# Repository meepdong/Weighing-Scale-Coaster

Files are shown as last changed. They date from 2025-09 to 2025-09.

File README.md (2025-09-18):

# Weighing Scale Coaster
A precision coffee scale built around the HX711 load cell amplifier, optimized for responsiveness and stability. Designed for baristas, tinkerers, and embedded engineers who care about both performance and personality.

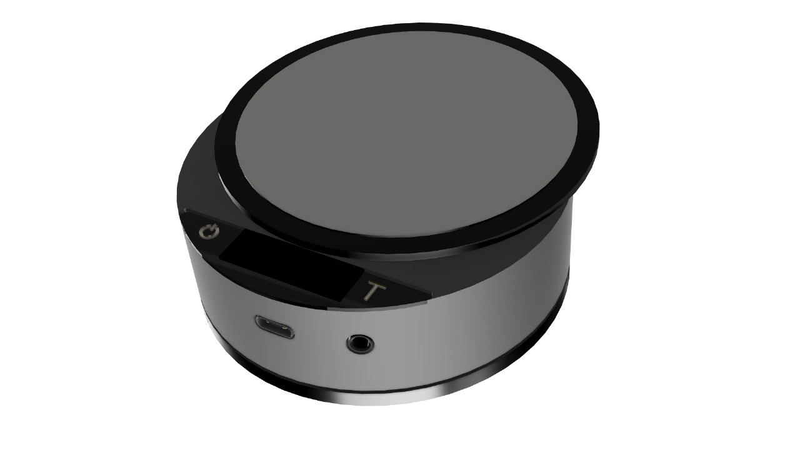
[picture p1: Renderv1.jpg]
Weighing Scale Coaster

## Features
• 	HX711-based load cell interface with high-resolution weight readings

• 	Reference-inspired filtering pipeline adapted from Analog Devices' weigh scale design

• 	OLED display with expressive dome-shaped eyes and smile animation

• 	Timer with short press toggle and long press reset

• 	Flicker-free weight display using hysteresis and trimmed averaging

• 	Designed for both Raspberry Pi Pico W and Seeed Studio XIAO ESP32-C6

## Hardware Overview
### Components
• 	HX711 Load Cell Amplifier

• 	5 kg Load Cell

• 	SSD1306 OLED Display (128×32)

• 	Two momentary push buttons (Tare + Timer) . To be replaced with capacitive touch 

• 	Microcontroller: Raspberry Pi Pico W or Seeed Studio XIAO ESP32-C6

## Wiring Table

| Pin on OLED | Pin on HX711 | Pin on Pico W | Pin on XIAO ESP32-C6 |
|---|---|---|---|
| VCC | VCC | 3.3V | 3.3V |
| GND | GND | GND | GND | 
| Data (DT) | DT | GPIO 16 | GPIO 10 |
| Clock (SCK) | SCK | GPIO 17 | GPIO 11 |
| OLED SDA | SDA | GPIO 4 | GPIO 4 | 
| OLED SCL | SCL | GPIO 5 | GPIO 5 |
| Tare Button | - | GPIO 18 | GPIO 6 |
| Timer Button  | - | GPIO 19 | GPIO 7 |

## Load Cell Algorithm
This project adapts the signal processing architecture from Analog Devices' weigh scale reference design to the HX711.
Filtering Pipeline

• 	Trimmed Moving Average: Removes min/max outliers from a rolling window to suppress noise while preserving step response.

• 	Step Detection: Detects real weight changes using dual-threshold logic and pre-fills the filter buffer to skip lag.

• 	Display Hysteresis: Prevents flicker by suppressing small changes below a threshold.

### Why It Works
• 	HX711 is a 24-bit sigma-delta ADC with built-in gain and ratiometric measurement.

• 	Filtering compensates for its limited noise-free resolution and slow sample rate.

• 	The result: smooth, stable, and responsive weight readings even with low-cost hardware.

## User Interaction

OLED shows timer and weight. Startup animation includes blinking eyes and a smile. A Hall effect sensor to be integrated for a lid-activated deep sleep and wake mode.

Future Improvements
• 	Calibration helper script for computing 

• 	BLE or Wi-Fi integration for remote brew tracking

• 	Capacitive touch buttons

Credits
Built by Maurice D'Moss, mechanical product design engineer with a passion for coffee and embedded systems.
Filtering architecture inspired by Analog Devices' weigh scale reference design.

## License

This project is licensed under the [Creative Commons Attribution-NonCommercial 4.0 International License](https://creativecommons.org/licenses/by-nc/4.0/).

You are free to use, modify, and share this project for personal and educational purposes.  
Commercial use is not permitted without explicit permission from the author.

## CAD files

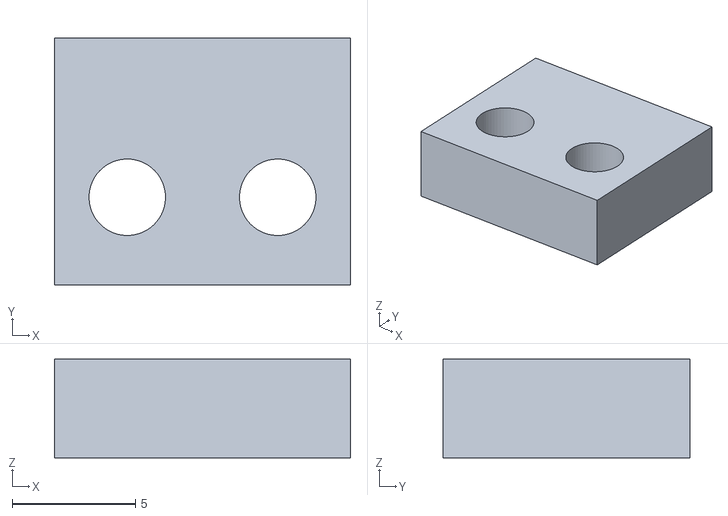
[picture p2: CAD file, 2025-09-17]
CAD/Spacer small.stl
12.0 x 10.0 x 4.00

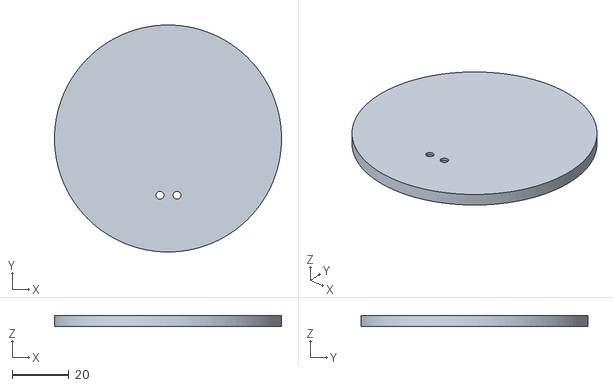
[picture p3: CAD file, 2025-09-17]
CAD/Plate test.stl
80.0 x 80.0 x 4.00

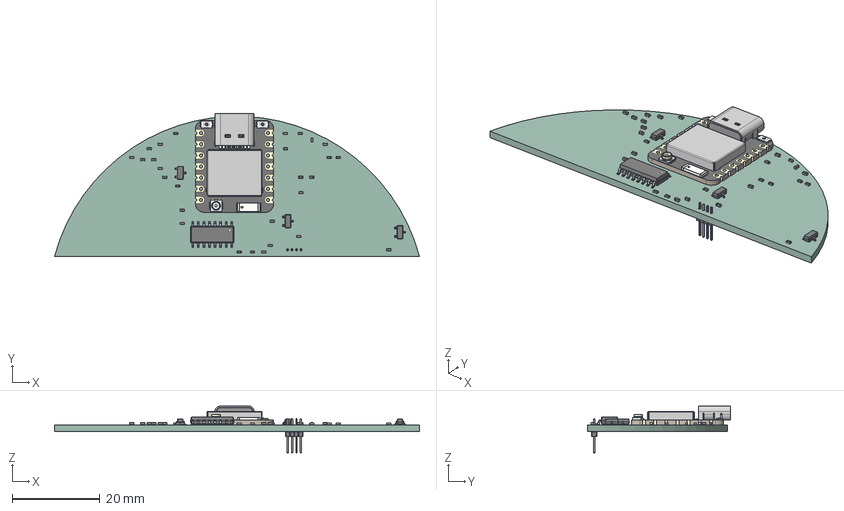
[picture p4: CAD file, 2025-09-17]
CAD/WeighingScalePCB.step
83.1 x 32.5 x 10.7 mm
SOIC-16_3.9x9.9mm_P1.27mm
C_0402_1005Metric x 16
R_0402_1005Metric x 12
SOT-23 x 3
BOSS-EXTRUDE14_8_
BOSS-EXTRUDE7_4_
BOSS-EXTRUDE7_3_
BOSS-EXTRUDE14_4_
BOSS-EXTRUDE14_2_
BOSS-EXTRUDE14_11_
BOSS-EXTRUDE7_7_
BOSS-EXTRUDE14_9_
BOSS-EXTRUDE14_3_
BOSS-EXTRUDE14_7_
MIRROR2
BOSS-EXTRUDE14_5_
BOSS-EXTRUDE14_12_
BOSS-EXTRUDE7_8_
BOSS-EXTRUDE7_1_
BOSS-EXTRUDE14_10_
BOSS-EXTRUDE7_9_
BOSS-EXTRUDE14_6_
BOSS-EXTRUDE14_1_
BOSS-EXTRUDE7_6_
BOSS-EXTRUDE7_2_
CUT-EXTRUDE5
BOSS-EXTRUDE7_5_
U.FL Connector v1
Shield
SKTAAAE010 v1 x 2
KH5220-A36 (Ceramic Antenna) v2
PinHeader_1x04_P1.00mm_Vertical
WeighingScalePCB_PCB

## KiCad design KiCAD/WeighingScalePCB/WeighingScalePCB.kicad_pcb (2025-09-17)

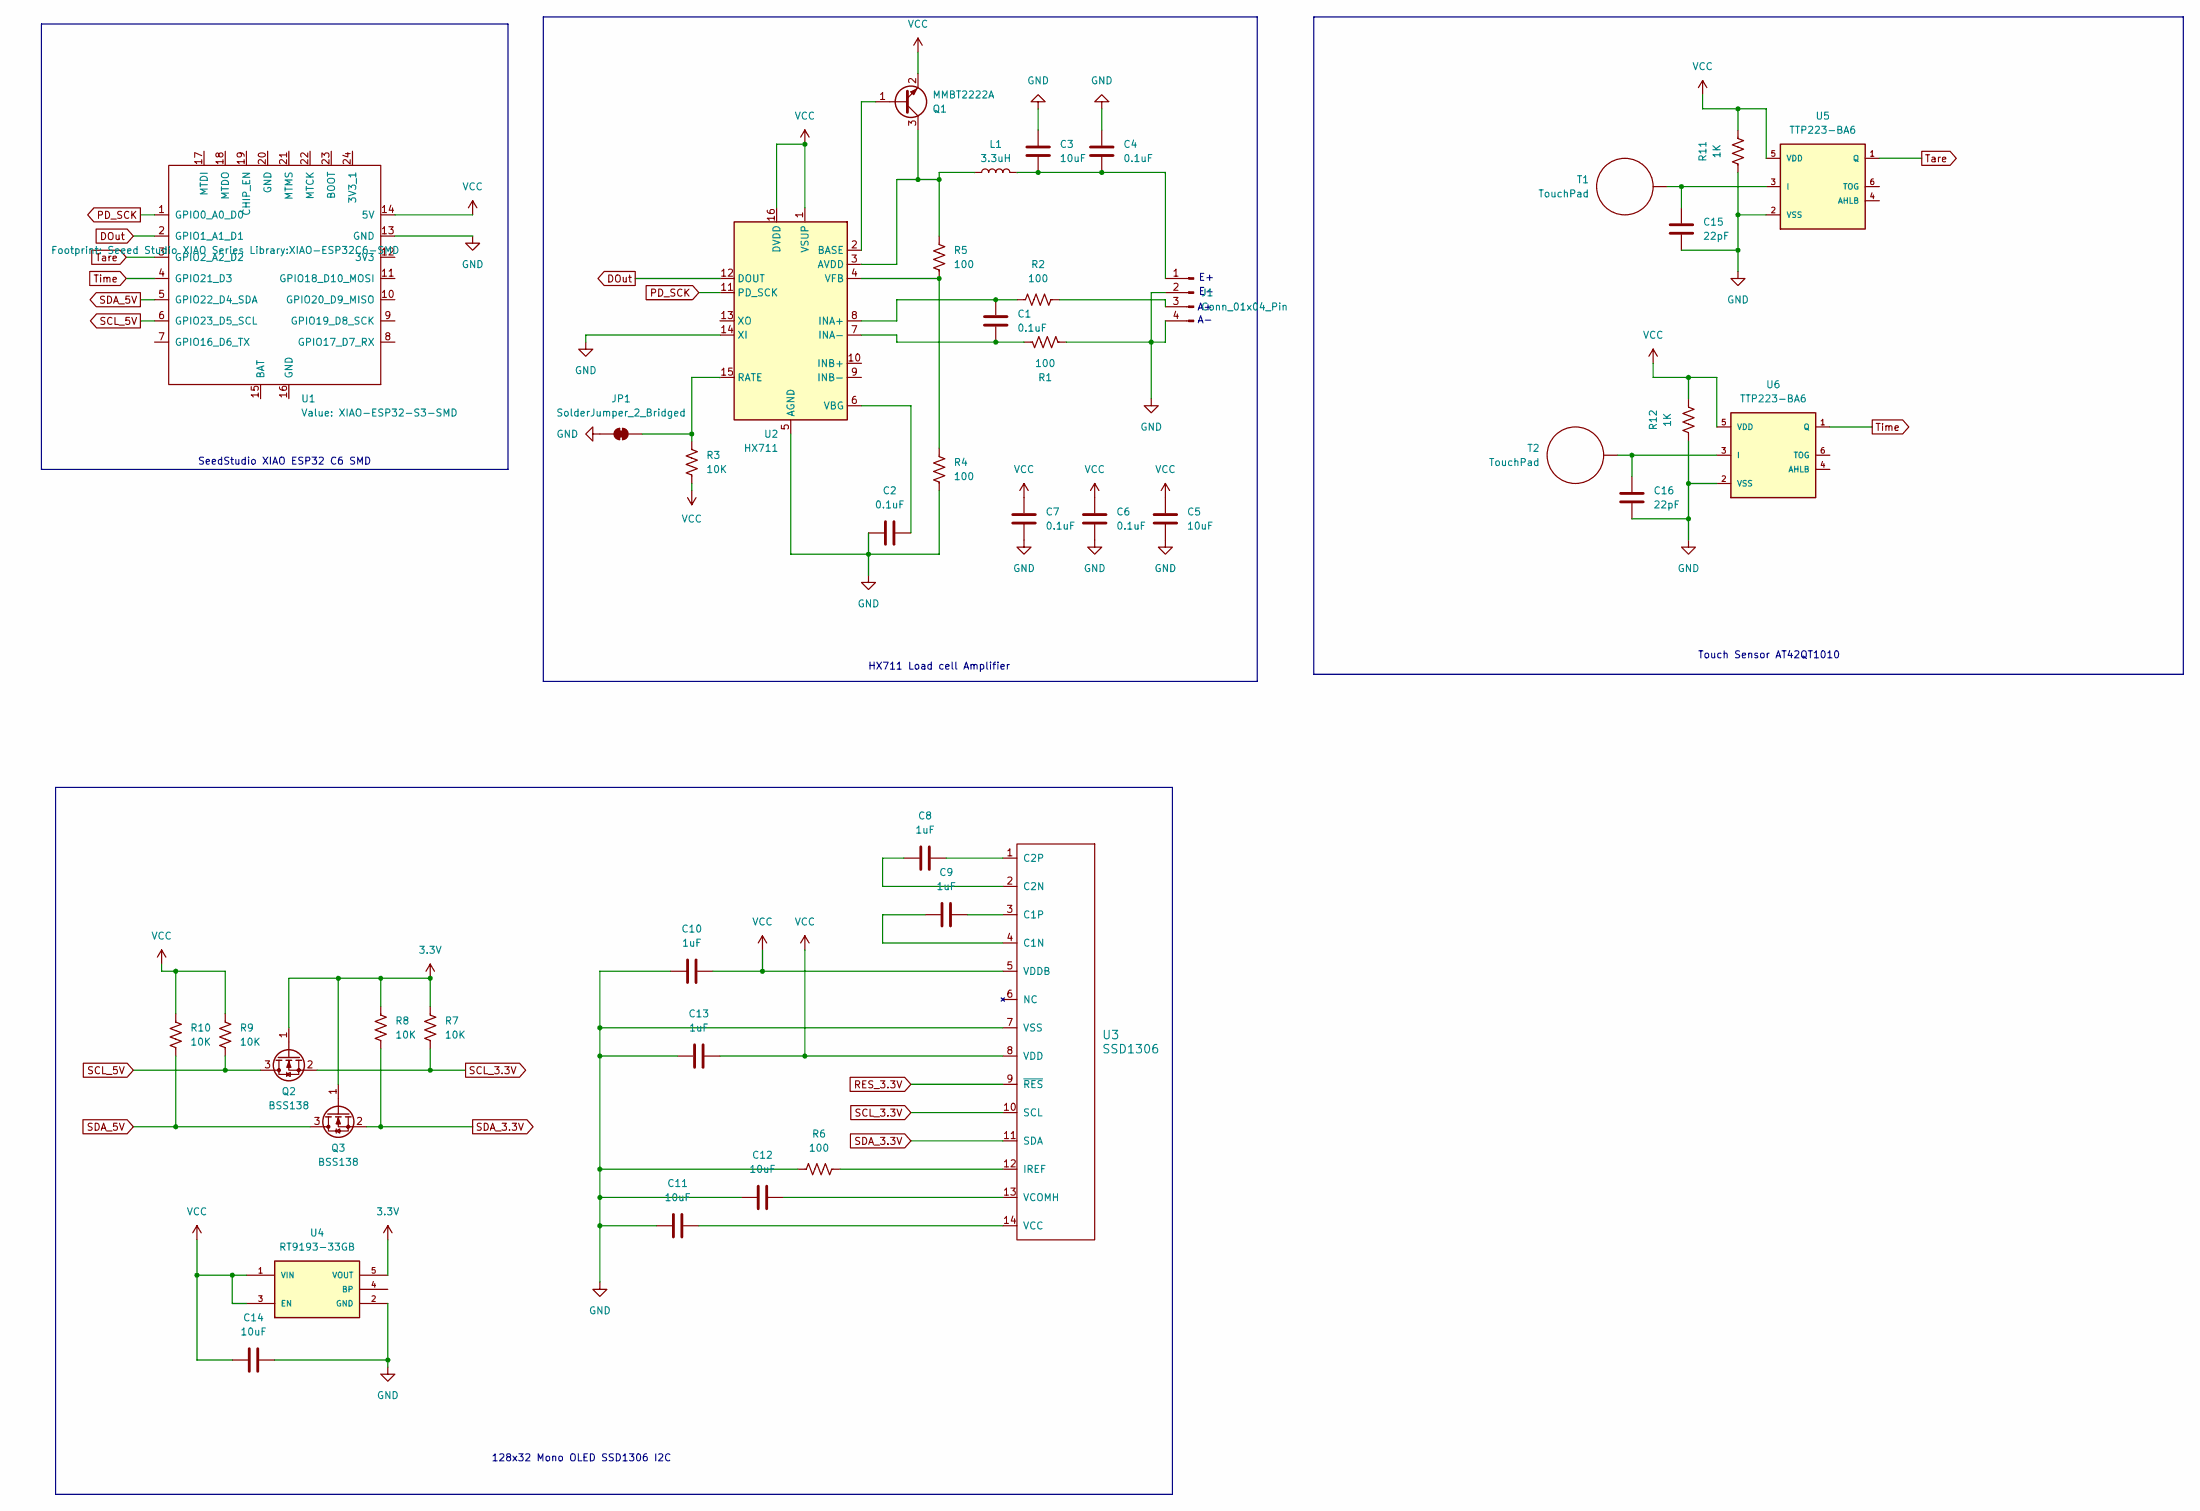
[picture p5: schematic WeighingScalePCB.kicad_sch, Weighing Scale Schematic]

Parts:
C1, C2, C4, C6, C7: 0.1uF; C_0402_1005Metric
C3, C5, C11, C12, C14: 10uF; C_0402_1005Metric
C8, C9, C10, C13: 1uF; C_0402_1005Metric
C15, C16: 22pF; C_0402_1005Metric
J1: Conn_01x04_Pin; PinHeader_1x04_P1.00mm_Vertical
JP1: SolderJumper_2_Bridged
L1: 3.3uH; L_Coilcraft_XxL4040
Q1: MMBT2222A; SOT-23
Q2, Q3: BSS138; SOT-23
R1, R2, R4, R5, R6: 100; R_0402_1005Metric
R3, R7, R8, R9, R10: 10K; R_0402_1005Metric
R11, R12: 1K; R_0402_1005Metric
T1, T2: TouchPad; Touch-Pad_10mm
U1: XIAO-ESP32-S3-SMD; XIAO-ESP32C6-SMD
U2: HX711; SOIC-16_3.9x9.9mm_P1.27mm
U3: SSD1306; SSD1306_OLED-0.91-128x32
U4: RT9193-33GB; SOT94P279X129-5N
U5, U6: TTP223-BA6; SOT23-6

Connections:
3.3V: Q2.1 (G), Q3.1 (G), R7.1, R8.1, U4.5 (VOUT)
DOut: U1.2 (GPIO1_A1_D1), U2.12 (DOUT)
GND: C2.1, C3.1, C4.1, C5.2, C6.2, C7.2, C10.1, C11.1, C12.1, C13.1, C14.2, C15.2, C16.2, J1.2, J1.4, JP1.1 (A), R1.1, R4.2, R6.2, R11.2, R12.2, U1.13 (GND), U2.5 (AGND), U2.14 (XI), U3.7 (VSS), U4.2 (GND), U5.2 (VSS), U6.2 (VSS)
unnamed: C3.2, C4.2, J1.1, L1.2
unnamed: J1.3, R2.1
unnamed: JP1.2 (B), R3.1, U2.15 (RATE)
unnamed: Q1.1 (B), U2.2 (BASE)
unnamed: L1.1, Q1.3 (C), R5.1, U2.3 (AVDD)
unnamed: C1.1, R2.2, U2.8 (INA+)
unnamed: C1.2, R1.2, U2.7 (INA-)
unnamed: C2.2, U2.6 (VBG)
unnamed: R4.1, R5.2, U2.4 (VFB)
unnamed: C9.1, U3.4 (C1N)
unnamed: C9.2, U3.3 (C1P)
unnamed: C8.1, U3.2 (C2N)
unnamed: C8.2, U3.1 (C2P)
unnamed: R6.1, U3.12 (IREF)
unnamed: C11.2, U3.14 (VCC)
unnamed: C12.2, U3.13 (VCOMH)
unnamed: C15.1, T1.1 (Pad), U5.3 (I)
unnamed: C16.1, T2.1 (Pad), U6.3 (I)
PD_SCK: U1.1 (GPIO0_A0_D0), U2.11 (PD_SCK)
RES_3.3V: U3.9 (~RES)
SCL_3.3V: Q2.2 (S), R7.2, U3.10 (SCL)
SCL_5V: Q2.3 (D), R9.2, U1.6 (GPIO23_D5_SCL)
SDA_3.3V: Q3.2 (S), R8.2, U3.11 (SDA)
SDA_5V: Q3.3 (D), R10.2, U1.5 (GPIO22_D4_SDA)
Tare: U1.3 (GPIO2_A2_D2), U5.1 (Q)
Time: U1.4 (GPIO21_D3), U6.1 (Q)
VCC: C5.1, C6.1, C7.1, C10.2, C13.2, C14.1, Q1.2 (E), R3.2, R9.1, R10.1, R11.1, R12.1, U1.14 (5V), U2.1 (VSUP), U2.16 (DVDD), U3.5 (VDDB), U3.8 (VDD), U4.1 (VIN), U4.3 (EN), U5.5 (VDD), U6.5 (VDD)

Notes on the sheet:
HX711 Load cell Amplifier
SeedStudio XIAO ESP32 C6 SMD
Touch Sensor AT42QT1010
128x32 Mono OLED SSD1306 I2C

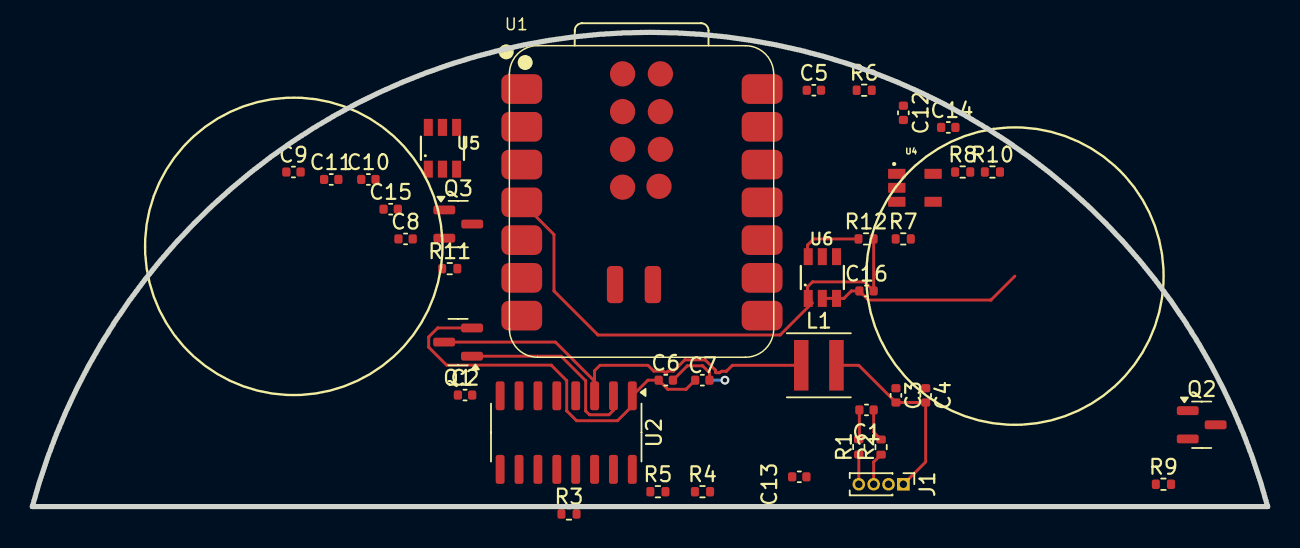
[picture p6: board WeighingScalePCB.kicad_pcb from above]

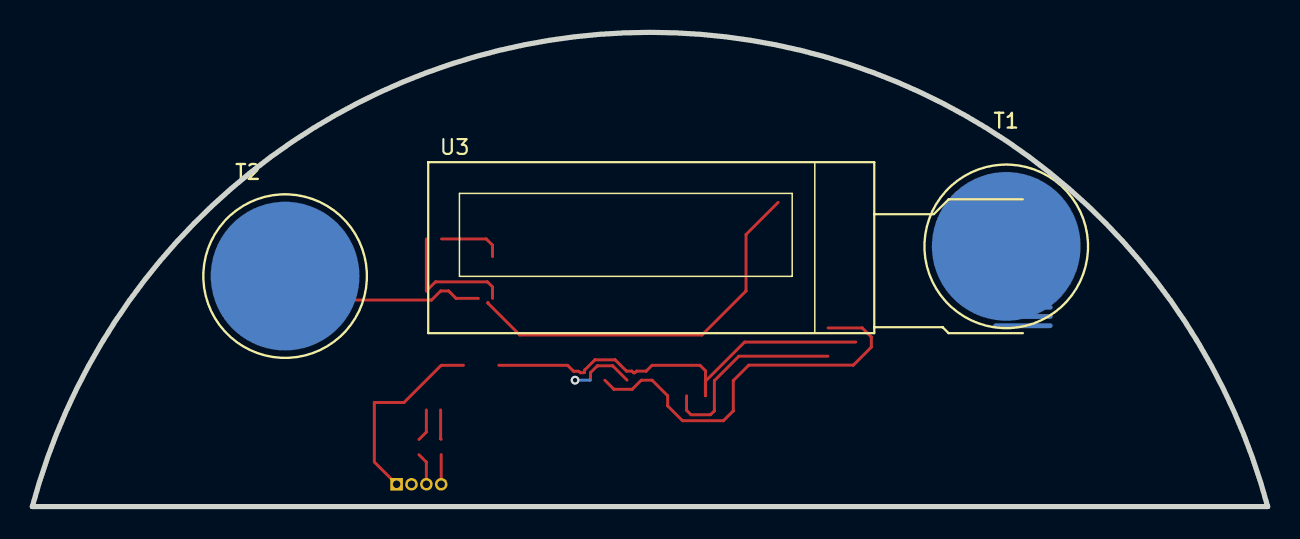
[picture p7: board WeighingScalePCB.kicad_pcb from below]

Board: 4 copper layers, 83.1 x 31.9 mm, 41 parts (3 on the bottom side), 29 nets.

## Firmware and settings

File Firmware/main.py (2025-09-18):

from machine import Pin, I2C
import ssd1306
import time
from hx711 import HX711

# =======================
# Pin Config (XIAO ESP32-C6)
# =======================
HX711_DT = 0
HX711_SCK = 1
OLED_SCL = 23
OLED_SDA = 22
BTN_TARE = 2
BTN_TIMER = 21

# =======================
# Calibration & Timing
# =======================
CALIBRATION_FACTOR = 38 / 24800
REFRESH_MS = 10
LONG_PRESS_MS = 1500

# =======================
# Reference-style Filtering
# =======================
TMA_WINDOW = 16
STEP_THRESHOLD_G = 0.8
PREFILL_CYCLES = 6
DISPLAY_HYST_G = 0.2

class TrimmedMovingAverage:
    def __init__(self, size=16):
        self.size = size
        self.buf = []
        self.prefill_cycles_remaining = 0

    def reset(self):
        self.buf = []
        self.prefill_cycles_remaining = 0

    def prefill(self, sample, cycles=6):
        self.buf = [sample] * min(self.size, max(1, len(self.buf) or self.size))
        self.prefill_cycles_remaining = max(0, cycles)

    def push(self, sample):
        if self.prefill_cycles_remaining > 0:
            self.buf = [sample] * len(self.buf)
            self.prefill_cycles_remaining -= 1
            return sample
        self.buf.append(sample)
        if len(self.buf) > self.size:
            self.buf.pop(0)
        return self.value()

    def value(self):
        n = len(self.buf)
        if n < 4:
            return sum(self.buf) / max(1, n)
        srt = sorted(self.buf)
        core = srt[1:-1]
        return sum(core) / len(core)

class StepDetector:
    def __init__(self, threshold):
        self.threshold = threshold
        self.prev_delta_exceeded = False

    def check(self, new_sample, current_avg):
        if current_avg is None:
            self.prev_delta_exceeded = False
            return False
        delta = abs(new_sample - current_avg)
        exceeded = delta > self.threshold
        is_step = exceeded and self.prev_delta_exceeded
        self.prev_delta_exceeded = exceeded
        return is_step

class DisplayHysteresis:
    def __init__(self, threshold_display_units):
        self.threshold = threshold_display_units
        self.last_display = None

    def decide(self, proposed_value):
        if self.last_display is None:
            self.last_display = proposed_value
            return proposed_value
        if abs(proposed_value - self.last_display) < self.threshold:
            return self.last_display
        self.last_display = proposed_value
        return proposed_value

# =======================
# Hardware Init
# =======================
i2c = I2C(0, scl=Pin(OLED_SCL), sda=Pin(OLED_SDA), freq=400000)
display = ssd1306.SSD1306_I2C(128, 32, i2c, addr=0x3C)
display.rotate()

hx = HX711(dout=HX711_DT, pd_sck=HX711_SCK)
btn_tare = Pin(BTN_TARE, Pin.IN, Pin.PULL_UP)
btn_timer = Pin(BTN_TIMER, Pin.IN, Pin.PULL_UP)

tma = TrimmedMovingAverage(size=TMA_WINDOW)
step = StepDetector(threshold=STEP_THRESHOLD_G)
disp = DisplayHysteresis(threshold_display_units=DISPLAY_HYST_G)

# =======================
# Eye Drawing
# =======================
def draw_dome_eye(cx, cy, rx, ry, pupil_offset):
    for dx in range(-rx, rx + 1):
        for dy in range(-ry, 1):
            if (dx*dx)/(rx*rx) + (dy*dy)/(ry*ry) <= 1:
                display.pixel(cx + dx, cy + dy, 1)
    for dx in range(-rx, rx + 1):
        display.pixel(cx + dx, cy, 1)
    for dx in range(-1, 2):
        for dy in range(-1, 2):
            display.pixel(cx + pupil_offset + dx, cy - 1 + dy, 0)

def draw_eyes(pupil_offset):
    display.fill(0)
    draw_dome_eye(40, 8, 5, 4, pupil_offset)
    draw_dome_eye(88, 8, 5, 4, pupil_offset)
    display.show()

def draw_smile():
    display.fill(0)
    draw_dome_eye(40, 14, 5, 4, 0)
    draw_dome_eye(88, 14, 5, 4, 0)
    for x in range(54, 74):
        y = int(32 - 0.04 * (x - 64) ** 2)
        display.pixel(x, y, 1)
    display.show()

def write_text():
    display.fill(0)
    display.text("Happy brewing!", 5, 15)
    display.show()

# =======================
# Startup Animation
# =======================
print("Intitialising......")
draw_eyes(-2)
time.sleep(0.5)
draw_eyes(2)
time.sleep(0.5)
draw_smile()
time.sleep(1.0)
write_text()
time.sleep(1.0)

hx.tare()
tma.reset()
disp.last_display = None
time.sleep(0.5)
print("Taring complete. Display is live.")

# =======================
# Timer State
# =======================
timer_running = False
elapsed_ms = 0
last_tick = time.ticks_ms()
timer_btn_pressed_time = None
long_press_handled = False

# =======================
# Main Loop
# =======================
while True:
    now = time.ticks_ms()
    dt = time.ticks_diff(now, last_tick)
    last_tick = now

    if timer_running:
        elapsed_ms += dt

    if btn_tare.value() == 0:
        hx.tare()
        tma.reset()
        disp.last_display = None
        time.sleep(0.3)
        print("Tare pressed")

    if btn_timer.value() == 0:
        if timer_btn_pressed_time is None:
            timer_btn_pressed_time = now
            long_press_handled = False
        elif not long_press_handled and time.ticks_diff(now, timer_btn_pressed_time) > LONG_PRESS_MS:
            elapsed_ms = 0
            timer_running = False
            long_press_handled = True
            print("Timer reset & stopped")
            time.sleep(0.3)
    else:
        if timer_btn_pressed_time is not None:
            if not long_press_handled and time.ticks_diff(now, timer_btn_pressed_time) <= LONG_PRESS_MS:
                timer_running = not timer_running
                print("Timer", "started" if timer_running else "stopped")
            timer_btn_pressed_time = None
            long_press_handled = False

    raw_val = hx.get_value()
    if raw_val is not None:
        weight_grams = -raw_val * CALIBRATION_FACTOR
        current_avg = tma.value()

        if step.check(weight_grams, current_avg):
            tma.prefill(weight_grams, cycles=PREFILL_CYCLES)

        filtered_weight = tma.push(weight_grams)
        displayed_weight = disp.decide(filtered_weight)

        if displayed_weight < -0.2:
            weight_text = "-{:.1f}g".format(abs(displayed_weight))
        elif displayed_weight < 0.2:
            weight_text = "0.0g"
        else:
            weight_text = "{:.1f}g".format(abs(displayed_weight))

        secs = elapsed_ms // 1000
        minutes = secs // 60
        seconds = secs % 60
        time_text = "{}:{:02d}".format(minutes, seconds)

        display.fill(0)
        display.text(time_text, 0, 0)
        display.text(weight_text, 0, 16)
        display.show()

        print("Raw: {:>10} | Weight: {:.2f} g | Display Weight: {} | Timer: {}".format(raw_val, displayed_weight, weight_text, time_text), end='\r')
    else:
        print("No valid reading", end='\r')

    time.sleep_ms(REFRESH_MS)

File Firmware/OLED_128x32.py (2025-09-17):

from machine import Pin
import time
from hx711 import HX711  # Ensure hx711.py is on your board

# === Pin assignments for XIAO ESP32-C6 ===
HX711_DT = 0   # Data pin from HX711 (DOUT)
HX711_SCK = 1  # Clock pin to HX711 (SCK)

# === Calibration factor ===
# Adjust this after calibration with a known weight
CALIBRATION_FACTOR = -38/24800

# === Initialize HX711 ===
hx = HX711(dout=HX711_DT, pd_sck=HX711_SCK)

print("HX711 raw + unfiltered weight test — press Ctrl+C to stop")
time.sleep(1)

# Optional: tare before starting
print("Taring...")
hx.tare()
time.sleep(0.5)
print("Tare complete.")

while True:
    raw_val = hx.get_value()
    if raw_val is not None:
        weight_grams = raw_val * CALIBRATION_FACTOR
        print("Raw: {:>10} | Weight: {:.2f} g".format(raw_val, weight_grams))
    else:
        print("No valid reading")
    time.sleep(0.2)  # ~5 readings per second
